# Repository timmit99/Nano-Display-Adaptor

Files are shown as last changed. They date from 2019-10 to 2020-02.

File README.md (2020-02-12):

# RepRap-Display-Controller
Arduino Nano compatable board to controll a RepRap display

This board maps an arduino nano's pins onto the 2 2x5 pin IDC cables needed for a RepRapDiscount Smart Controller or RepRapDiscount Full Graphic Smart Controller.

<br />This work is licensed under a <a rel="license" href="http://creativecommons.org/licenses/by-nc/3.0/us/">Creative Commons Attribution-NonCommercial 3.0 United States License</a>.

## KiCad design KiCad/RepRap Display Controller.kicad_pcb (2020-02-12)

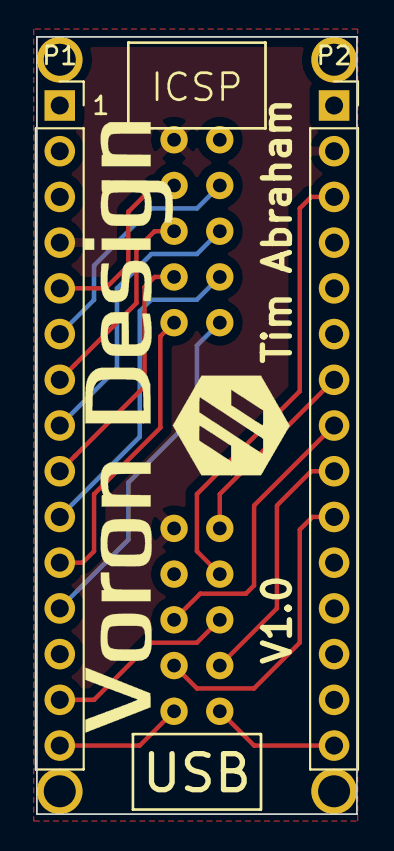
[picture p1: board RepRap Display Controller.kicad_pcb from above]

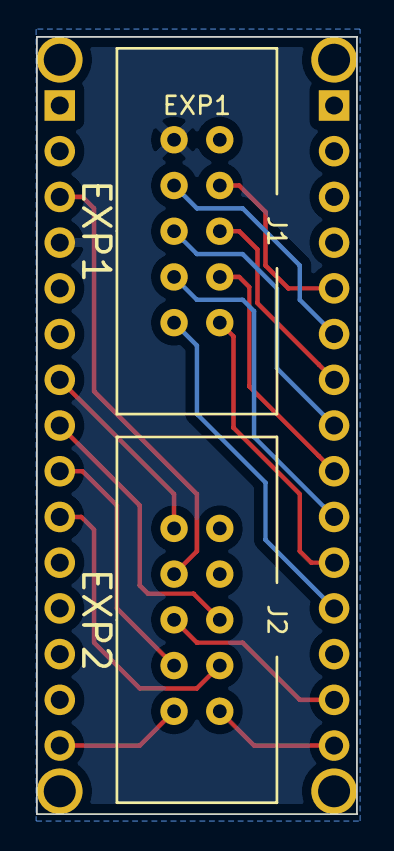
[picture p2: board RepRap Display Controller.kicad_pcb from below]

Board: 2 copper layers, 17.8 x 43.2 mm, 8 parts (2 on the bottom side), 18 nets.

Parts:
J1: EXP1; Shrouded_2x5_pin_header
J2: EXP2; Shrouded_2x5_pin_header
P1: Digital; PinSocket_1x15_P2.54mm_Vertical
P2: Analog; PinSocket_1x15_P2.54mm_Vertical
P3, P4, P5, P6: CONN_01X01; 1pin_Nano

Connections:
+5V: J1.10, P2.4
/2: J1.7, P1.5
/3(**): J1.8, P1.6
/4: J1.5, P1.7
/5(**): J1.6, P1.8
/6(**): J1.3, P1.9
/7: J1.4, P1.10
/8: J1.1, P1.11
/9(**): J1.2, P1.12
/11(**/MOSI): J2.6, P1.14
/12(MISO): J2.1, P1.15
/13(SCK): J2.2, P2.15
/A2: J2.3, P2.10
/A3: J2.4, P2.9
/A4: J2.5, P2.8
/A5: J2.10, P2.7
/Reset: J2.8, P2.3
GND: J1.9, J2.9, P1.4, P2.2

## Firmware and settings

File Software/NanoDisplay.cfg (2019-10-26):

# Add a "[include NanoDisplay.cfg]" to the end of your printer.cfg 

[mcu display]
#    mcu for the display
serial: /dev/serial/by-id/usb-1a86_USB2.0-Serial-if00-port0
pin_map: arduino
restart_method: arduino

[display]
lcd_type: st7920
cs_pin: display:EXP1_4
sclk_pin: display:EXP1_5
sid_pin: display:EXP1_3
encoder_pins: ^display:EXP2_3, ^display:EXP2_5
click_pin: ^!display:EXP1_2
#kill_pin: ^!display:EXP2_8

[output_pin beeper]
pin: display:EXP1_1

[board_pins display]
aliases:
    # Common EXP1 header found on many "all-in-one" ramps clones
    EXP1_1=ar8,  EXP1_3=ar6,  EXP1_5=ar4,  EXP1_7=ar2,  EXP1_9=<GND>,
    EXP1_2=ar9,  EXP1_4=ar7,  EXP1_6=ar5,  EXP1_8=ar3,  EXP1_10=<5V>,
    # EXP2 header
    EXP2_1=ar12, EXP2_3=ar16, EXP2_5=ar18, EXP2_7=ar49, EXP2_9=<GND>,
    EXP2_2=ar13, EXP2_4=ar17, EXP2_6=ar11, EXP2_8=<RST>,EXP2_10=<RST>
    # Pins EXP2_1, EXP2_6, EXP2_2 are also MISO, MOSI, SCK of bus "spi"
    # Note, some boards wire: EXP2_8=<RST>, EXP2_10=ar41

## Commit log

2019-10-18 Initial Commit
    Board designed to interface an Ardunio Nano to a repara 12864 display or the 2016 displays using 2 x 10 pin IDC cables
    [RepRap Display Controller.kicad_pcb, RepRap Display Controller.sch]
2019-10-18 Reorganization and Klipper Config
    Files organized into folders for ease of navigation. Also added an UNTESTED Klipper .cfg file that can be included into the main printer.cfg to enable this disaply adaptor.
    [NanoDisplay.cfg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]
2019-10-26 Update NanoDisplay.cfg
    Changing pin names to work properly=P
    [NanoDisplay.cfg]
2020-02-12 Added license and versioning to PCB
    Added V1.0 to board for proper versioning going forward and CC BY-NC license.
    Basically, Full reign to share and modify as long as it is NOT used commercial and retains all attribution to the source.
    [RepRap Display Controller.kicad_pcb, RepRap Display Controller.sch]
2020-02-12 Gerber Update for V1.0
    Pushed updated gerbers for V1.0
    [RepRap Display Controller-B_Cu.gbr, RepRap Display Controller-B_Mask.gbr, RepRap Display Controller-B_SilkS.gbr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]
2020-02-12 Project Zip
    [RepRap Display Controller.kicad_pcb]
